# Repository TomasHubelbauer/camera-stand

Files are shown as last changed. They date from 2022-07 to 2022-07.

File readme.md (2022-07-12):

# Camera Stand

This repository hosts the development of a 3D model for a 3D printed part that
is used to mount my camera to use as a webcam behind my monitor.

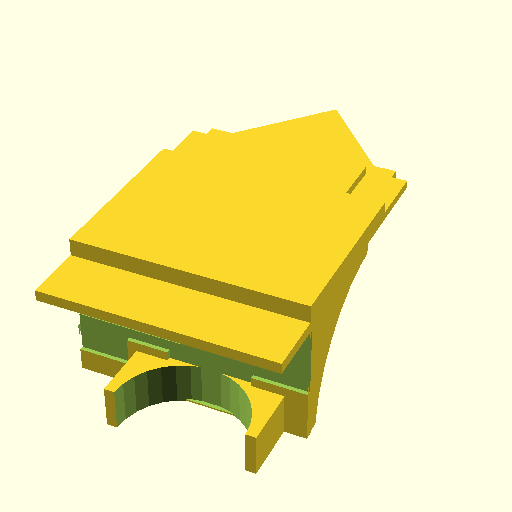
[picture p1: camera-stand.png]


## Status & Goal

This part should be complete now provided the test print fits.

The goal of this part is to be a mount that fits into the VESA mount of my
monitor and extends a flat platform onto which my camera can sit. The platform
has hole for the dummy battery power plug as well as a recess in the shape of
the camera's body so that the camera doesn't shift away from the central point
when I turn it on and off. The recess/track that fits the camera's body in the
flat of the platform also extends to make room for the camera's grip handle and
the lens which both extend to contour of the camera as projected on the surface.

## Process & Files

Note: this process is implemented in [`slice.sh`](slice.sh). The simplified
process now is to open OpenSCAD and VS Code side by side, make changes in VS
Code and see them reflect in OpenSCAD and on each iteration I am happy with run
`./slice.sh` which generates STL, slices it to GCode and export a 3MF directory
of the PrusaSlicer project file as well.

I use OpenSCAD to design the part. I split my screen into VS Code on the left
and OpenSCAD on the right. OpenSCAD is configured to hide the editor and with
this setting on, it will automatically refresh whenever the source file is
changed in VS Code. In VS Code, I use the OpenSCAD extension for VS Code for
syntax highlighting and auto-complete.

Once I am happy with the current iteration, I render the file out to an SLT in
OpenSCAD (configured to put out ASCII STL by default) and drag it into a new
project in PrusaSlicer. Next, I orient it for the speed of printing and less so
for the strength of the resulting part (since it is just an iteration for now)
and slice it there. Once sliced, I save the PrusaSlicer project and the GCode.

Since PrusaSlicer projects are 3MF files which are binary (they are [OPC] ZIP
archives of several files), I use a hand-made script that I run after I have
saved the 3MF file to extract it into a directory by the same name to help diff.

[OPC]: https://en.wikipedia.org/wiki/Open_Packaging_Conventions

- `slice.sh` is the script that generates GCode and 3MF directory (not file)
- `camera-stand.gcode` is the GCode generated by PrusaSlicer for my Prusa MK3S
- `camera-stand.png` is the OpenSCAD render of the model generated in `slice.sh`
- `camera-stand.scad` is the source code authored by me
- `camera-stand.stl` is the ASCII STL rendered out by OpenSCAD
- `camera-stand.3mf` is the directory where `./3mf-zip-dir` extracts PrusaSlicer
  project file by the same name (it is an OPC ZIP binary not fit for versioning)

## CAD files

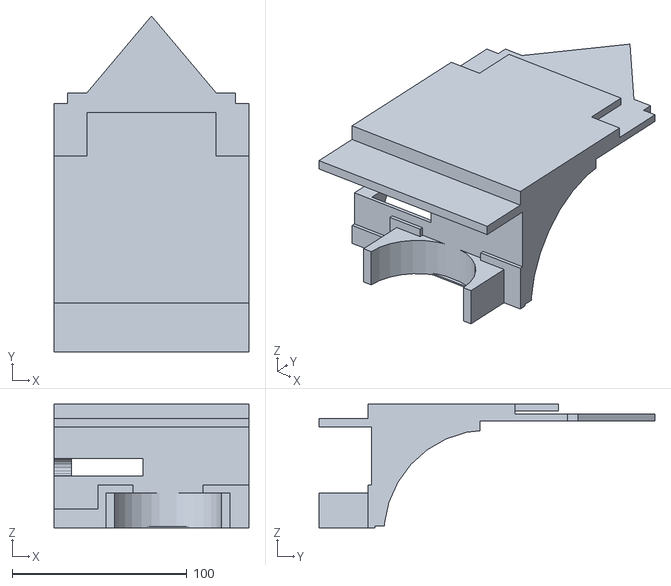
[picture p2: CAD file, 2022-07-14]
camera-stand.stl
111.2 x 192.0 x 70.7

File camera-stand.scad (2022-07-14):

// The distance between the right side of the left screw and left side of the
// right screw connecting the VESA mount plate and the screen (as seen when
// sitting in front of the screen)
screws_distance = 96;

// The distance between the top sides of the two flaps that presumably have the
// screw holes for the 75x75 mm version of the VESA mount
// This distance is important, because it is the maximum width for something to
// be able to slot between the screws and these flaps in order to go deep into
// the gap between the VESA mount plate and the back of the monitor.
flaps_distance = 74;

// The length of the surface of the flap beneath the screw that needs to be
// accounted for for the main rectangular leg to be narrower by in order to be
// able to slot deep into the gap between the VESA mount plate and the monitor
flap_width = (screws_distance - flaps_distance) / 2;

// The gap between the back of the screen and the flat side of the VESA mount
// plate facing the screen - the thickness of a support leg that fits there
plate_screen_gap = 4;

// The distance between the top point of the VESA mount plate arc and the top
// side of the left and right top screws connecting the plate and the screen
// (as seen when sitting in front of the screen)
tip_screw_distance = 30;

// The distance between the top point of the VESA mount and the top of the flaps
// on the plate that prevent slotting anything below this depth unless it is at
// most as wide as the distance between the flaps.
tip_flap_distance = 36;

// The depth between the top point of the VESA mount plate arc and the possible
// flaps that could collide with a box slotted in between the screen and the
// mount plate between the two top screws
// I've test-fitted to be up to 115 mm deep and there should be no other flaps
// so it theoretically can go all the way below the monitor, but there is only
// limited value to making this too large as there are diminishing returns on
// the snugness of the assembly compared to the printing time.
tip_pit_depth = 80;

// The diameter of a single screw used to calculate the gap between two parts
// that sit supported on and by the screw when bridged over their tops
screw_diameter = 3.6;

// The thickness of the VESA mount plate the two rectangular legs sit against
// the sides of
// This is not exact, I am affording some play for ease of slotting the part
// onto the edge of the plate, but not too much so it remains snug and sturdy.
plate_thickness = 1.7;

// The size of the square columns that sit at the outside of the top left and
// right screws of the VESA mount plate forming a hook together with the main
// rectangle leg and the surface that connects the three legs together to make
// a double hook
square_leg_size = 4;

// The distance from the left side to the right side of the whole leg assembly
// (left leg column, left screw, rectangular leg, right screw, right leg column)
leg_bridge_width = square_leg_size * 2 + screw_diameter * 2 + screws_distance;

// The thickness of the arch that connects the two main surfaces
brace_width = 10;

// The radius of the cylinder that cuts out the arch shape in the brace
arch_radius = 60;

// The rectangular leg that slots in between the screen back and the VESA mount
// plate on one axis and the two top screws on the plate on the other axis
linear_extrude(plate_screen_gap) polygon([
  // The origin point
  [0, 0],
  // The widest distance covering the length between the side square legs
  [leg_bridge_width, 0],
  // The first point that makes the bridge line over the screw
  [leg_bridge_width, tip_screw_distance],
  // The second point of the screw bridge line, shifted by screw width
  [leg_bridge_width - square_leg_size - screw_diameter, tip_screw_distance],
  // The surface that sits on the flap close to the screw over the flap's length
  [leg_bridge_width - square_leg_size - screw_diameter, tip_flap_distance],
  // The other side of the flap top surface that doesn't go deeper than this
  [leg_bridge_width - square_leg_size - screw_diameter - flap_width, tip_flap_distance],
  // The first point of the main rectangular leg that slots between the screws and flaps
  [leg_bridge_width / 2, tip_pit_depth],
  // The second point of the main rectangular leg that goes deep into the plate/screen gap
  [leg_bridge_width / 2, tip_pit_depth],
  // The first point of the top of the other flap that the rectangular leg is narrower by
  [square_leg_size + screw_diameter + flap_width, tip_flap_distance],
  // The second point of the top surface of the second flap next to the main leg
  [square_leg_size + screw_diameter, tip_flap_distance],
  // The first point over the bridge surface that makes the hook around the second screw
  [square_leg_size + screw_diameter, tip_screw_distance],
  // The second point over the second screw bridge layer, shifted by the screw diameter
  [0, tip_screw_distance],
]);

// The length of the channel the dummy battery plug goes into
gap_width = 50.6;

// The top surface that bridges the gap between the rectangular legs that hug
// the flat sides of the VESA mount plate
translate([0, -plate_screen_gap, 0]) cube([leg_bridge_width, plate_screen_gap, plate_screen_gap * 2 + plate_thickness]);

// The other rectangular leg that hugs the flat side of the VESA mount plate
// directed towards the wall as opposed to towards the back of the monitor
translate([square_leg_size + screw_diameter + flap_width, 0, plate_screen_gap + plate_thickness]) cube([flaps_distance, 25, plate_screen_gap]);

difference() {
  union() {
    // The vertical extension to raise the surface to the monitor top edge level
    translate([0, -84, 0]) cube([leg_bridge_width, 80, plate_screen_gap * 2 + plate_thickness]);

    track_offset = 12;
    track_size = 33;
    track_limit = track_offset + track_size;

    // The surface the camera sits on itself, perpendicular to the previous column
    difference() {
      translate([0, -84, -61]) cube([leg_bridge_width, 4, 70]);

      // The track in which the camera sits so it doesn't shift back and forth
      translate([0, -85, -3.5 - track_limit + track_offset]) cube([leg_bridge_width, 3, track_limit - track_offset]);
    
      // The cutout for the camera's grip handle to not crash with the track
      translate([0, -85, -2.3 - track_limit + track_offset - 15 + .1]) cube([25, 3, 15]);

      // The cutout for the camera's lens which also extends to the bottom plate
      translate([60 - (40 / 2) + 5, -85, -2.3 - track_limit + track_offset - 25 + .1]) cube([40, 3, 25]);
    }

    lens_diameter = 61;
    lens_radius = lens_diameter / 2;

    difference() {
      translate([60 - (40 / 2) + 5 + (40 / 2) - lens_radius - 5, -112, -61]) cube([lens_diameter + 10, lens_radius, 20]);
      translate([60 - (40 / 2) + 5 + (40 / 2), -112, -61.5]) cylinder(21, lens_radius, lens_radius);
    }

    plate_height = lens_radius - 2.5;
    back_thickness = 5;

    // The back plate for the camera to lean against without rocking back and forth
    translate([0, -84 - plate_height, -3.5]) cube([leg_bridge_width, plate_height, back_thickness]);
  }

  // A gap in the surface for the camera dummy battery power adapter plug to go through
  translate([-1, -85, -31.5]) cube([gap_width + 1, 10, 10]);
}

// The middle support arch holding the horizontal surface to the vertical column
difference() {
  translate([(leg_bridge_width - brace_width) / 2, -80, -arch_radius]) cube([brace_width, arch_radius, arch_radius]);
  translate([(leg_bridge_width - (brace_width + 2)) / 2, -15, -arch_radius - 5]) rotate([0, 90, 0]) cylinder(brace_width + 2, arch_radius, arch_radius);
}

// The left support arch holding the horizontal surface to the vertical column
difference() {
  translate([leg_bridge_width - brace_width, -80, -arch_radius]) cube([brace_width, arch_radius, arch_radius]);
  translate([leg_bridge_width - (brace_width + 2) + 1, -15, -arch_radius - 5]) rotate([0, 90, 0]) cylinder(brace_width + 2, arch_radius, arch_radius);
}

// The right support arch holding the horizontal surface to the vertical column
difference() {
  translate([0, -80, -arch_radius]) cube([brace_width, arch_radius, arch_radius]);
  translate([-1, -15, -arch_radius - 5]) rotate([0, 90, 0]) cylinder(brace_width + 2, arch_radius, arch_radius);
  translate([-1, -75, -26.5]) rotate([0, 90, 0]) cylinder(12, 5, 5);

  // The same gap as above to cut through the arch in addition to the platform
  translate([-1, -85, -31.5]) cube([gap_width + 1, 10, 10]);
}

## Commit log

2022-03-13 Design the basic shapes to test fit
    I measured the dimensions using a sheet of paper I kept cutting off piece by piece, because it is not easy to get access behind the screen with calipers and I am not going to dismount the screen to m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
    [camera-stand.scad, camera-stand.stl]
2022-03-13 Expand the PrusaSlicer 3MF project for tracking
    From now on with each change I will also track the unzipped version of the 3MF.
2022-03-13 Use the thumbnail in the readme and explain the flow
    I added a few words about how I work so it is clear why the 3MF directory exists and what is the source of truth: OpenSCAD > ASCII STL > 3MF directory.
2022-03-13 Include the script name in the readme
    The VS Code integrated terminal is good at remembering the last used command, so I don't need to type the script name a whole lot, but in case I ever do and I don't feel like typing or tabbing, it is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
2022-03-13 Configure the GCode file name format for better versioning
    By default the format contains variable stuff that would result in carrying multiple versions of the file side by side, instead of carrying a history of a single file. By changing the format to use just the file name, this is avoided.
    This is configured in Print Settings (Expert) > Output file > Output filename format.
2022-03-13 Track the PrusaSlicer generated GCode
    I have finally figured out how to track the project file so now I was able to slice the model and here is the GCode for my printer. The next revisions will have SCAD, STL, 3MF and GCODE file changes 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
2022-03-13 Change to a fit testing box for the new layout idea
    The monitor mount has two parts which connect using a track for one to go into the other and are secured together using screws. I did not have these screws there and tightened before. I added them and now the distance between the mount plate and the wall is much shorter so the previous revision doesn't fit at all. I've decided to change course and instead print a stand that will only attach to the mount part that is secured to the monitor not primarily the one attached to the wall.
    [camera-stand.scad, camera-stand.stl]
2022-03-13 Update dimensions and form into a hook platform over the VESA mount
    I need to learn to use the calipers properly, because the previous fit test box was too short on the X (but the other dimensions were correct).
    This shape should be able to sit snugly on the VESA mount edge and secured by the two screws so it doesn't move in any direction.
    [camera-stand.scad, camera-stand.stl]
2022-03-13 Revert the GCode file name config
    I tend to start a new PrusaSlicer project and just delete the 3MF directory in this repository, save the new project and rebuild it.
    This setting is not preserved when I create a new project and I have found it is not too much of an issue since I can just select the old GCode file when exporting GCode and it will take its name and replace it, so the default suggested name is no problem. The modal window even remembers the last directory, so it is quite literally only a single click to solve this problem.
    I could probably set this in some sort of a profile file and have it be the default for new prints, but I don't want that for prints that are not versione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
2022-03-13 Split the readme into Status and Process sections
    The process section is important so that I can remember this workflow if I ever get back to this at a later date.
    The status section captures the goal as well as the current state of the part as it is undergoing development. Once done, I will reflect that in this section.
2022-03-13 Redesign the rectangular slot that goes between the screen and the mount
    I have messed up before, the screw slots need to be at the right distance from the tip of the plate arc, not right beneath its level. I've reduced the design to just this slot for now and I will tweak it until it is good and then continue designing for the other part of the plate.
    [camera-stand.scad, camera-stand.stl]
2022-03-13 Increase screw diameter for clearance and add opposite side rectangular leg
    The screw slot is too tight because I made it the exact screw diameter and the nozzle diameter is not a perfect division of that number. I added an extra give hoping to accomodate the screws better.
    I also added a draft slot for the leg on the opposite side of the VESA mount plate.
    [camera-stand.scad, camera-stand.stl]
2022-03-13 Increase screw diameter for even more clearance and shrink back plate
    The screw slots still do not fit snugly around the screw so I've bumped the clearance up even more. On top of this, I have shrunk the back plate to make sure it does not collide with the flaps coming up from the plate, which would probably not happen with its current depth but would have happened if I prolonged it later.
    [camera-stand.scad, camera-stand.stl]
2022-03-14 Print plate-screen gap depth test fit piece in vase mode
    I know the dimensions of the gap in two axes which give me the rectangular main leg footprint, however, I don't know how deep this gap can go, so I'm trying to see if 100 mm is too much or will still fit.
    I have measured the distance between the flaps on the mount plate, it is 75 mm as compared to the distance between the screws, which is 96 mm. This means the main leg needs to be at most 75 mm thick, not 96 mm, after a certain depth (the distance between the flaps and the screws). I have not measured this exact depth yet, will do so after the test fit.
    I'm printing with no top or bottom solid layers or infill and in vase mode so I g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
    [camera-stand.scad, camera-stand.stl]
2022-03-14 Shape the main leg accounting for the flaps
    Now that I have measured the relevant dimensions, I am able to make the main rectangular leg narrower to avoid colliding with the flaps in the VESA mount (that I presume are there to support its 75x75 mm variant as opposed to 100x100 mm I am using).
    I am still printing in vase mode, but I have added a single solid bottom layer to make sure the shape really fits and the outline doesn't just get squished. I might need to make the leg one bit more narrow if it doesn't after this test fit.
    [camera-stand.scad, camera-stand.stl]
2022-03-14 Increase flap distance to make the model fit
    Previous test fit did not go accoding to plan, it seems the value for the flap distance I measured on the other side of the plate previously when making the other, currently hidden flat rectangular leg, is a better fit.
    I might adjust this even more if this still won't fit.
    [camera-stand.scad, camera-stand.stl]
2022-03-14 Add the other rectangular leg to test fit both at the same time
    The width of the rectangular leg is 74 mm as verified by the last test fit. I am winding a 1.6 mm mount plate thickness as 2 mm seemed to have too much give. I've also made the other rectangular leg go a bit deeper into the mount edge, but left room so that it would for sure fit. This whole assembly should fit now. If it does, it will be time to add the spacer part and the top flat layer to sit the camera on to it.
    [camera-stand.scad, camera-stand.stl]
2022-03-14 Reorient for slower printing but without irremovable supports
    I made a mistake trying to print the part laying flat before, because the support in the thin slot was impossible to remove and I permanently bent the part with still some support left trying to do it. I will print in a standing orientation now and to prevent layer shifting and other bad stuff, I have increased perimeter enough so that only the base will have infill and the rest of the model will be solid inside. This should give it enough strength to print cleanly and last. I have also added a lot of brim hoping it would help keep the object steady while printing.
    [camera-stand.scad, camera-stand.stl]
2022-03-16 Simplify the shape of the main leg for faster printing
    This triangular shape will make it easier to fit between the screws and the flaps and the bridge surfaces over the screws and the flaps should still keep the piece level and sturdy. Maybe this triangular part could be forgone completely and sturdiness could be derived solely from the fit over the edge of the mount plate, but I don't want to rely on that alone yet as I am still experimenting with the plate thickness which will make the piece fit easily but not have too much play.
    I have not updated the 3MF and the GCode as I am not printing this, I will adjust the plate thickness in the next commit and do a test print then.
    [camera-stand.scad, camera-stand.stl]
2022-03-16 Increase gap for plate side mounting
    I have removed the dimension to make this part slottable into another, I am thinking I will print this as a single part after all since the gap depth does not need to extend all so much.
    I have updated PrusaSlicer which changed the settings diff a little bit, but that's unrelated to the geometry change.
    [camera-stand.scad, camera-stand.stl]
2022-03-18 Extend the stand to make camera level at monitor top edge
    I have pretty much eyeballed these dimensions and I am going to print for a test fit now.
    The hole is there to make room for the wall plug of the dummy battery adapter.
    [camera-stand.scad, camera-stand.stl]
2022-03-18 Shift and enlarge top surface and add support brace
    I think I have the height sort of okay, but the previous extension of the surface to both sides made it crash to the wall and also I misplaced the dummy battery plug hole. The hole would still have been okay, just weirdly placed, but the crashing of the surface to the wall caused the whole assembly to not be able to fit onto the edge of the mount plate.
    It was also too narow so the camera would cause it to tip forward and since I had to break off the support flap on the back, it would not resist because it was not holding onto both sides of the mount plate.
    I was not sure whether the surface would be able to hold the weight of the camera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
    [camera-stand.scad, camera-stand.stl]
2022-03-31 Enlarge the gap for the power plug
    The power club is not straight but angled and as of current it doesn't fit great into the gap and it limits the camera's movement a lot. A larger gap should allow more maneuverability and if it is still not enough, I wil instead make it a straight-up cutout.
    [camera-stand.scad, camera-stand.stl]
2022-07-12 Make the gap the right size for the plug and enlarge the support arch
    I think I finally have the dimensions down for the plug. At least I hope so. The arch I made larger because there is nothing preventing it from being larger in terms of obstructing from the screen and it looks better this way.
    [camera-stand.scad, camera-stand.stl]
2022-07-12 Cut out tracks for the contour of the camera's body
    The track includes the body itself as well as the hand grip and the lens which both need room to not clash with the surface as the camera body sinks the 2 mm into the track cutout.
    [camera-stand.scad, camera-stand.stl]
2022-07-12 Update the readme with current status and clear done todos
    The part should be done now provided the test print fits.
2022-07-13 Add a wall the camera can lean against to sit in the cradle
    This wall is there to prevent the camera from rocking back when removing and putting back the lens cover as well as to provide additional support for when the hot shoe light cube is being turned on and off (which puts downward and slightly back-facing pressure on the camera).
    [camera-stand.scad, camera-stand.stl]
2022-07-13 Adjust the position of the lens track cutout
    It was off center and according to my measurements, a 5 mm shift to the right should just about fix it.
    [camera-stand.scad, camera-stand.stl]
2022-07-13 Triplicate the support arches
    I returned the original thickness as I think it will look better after all and also decided to triplicate the arch as I think it will help with the downward pressure applied to the camera as I turn o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
    [camera-stand.scad, camera-stand.stl]
2022-07-13 Fix the dummy battery plug hole dimensions
    I goofed out and placed the hole over the area where the plug cover rotates over to when the camera plug is exposed, but the area where the plug hole and the plug on the cable connect together was not accounted for. Also the cable and the plug on it need room to bend out of the way. I made the slit wide enough to accomodate for all this now - I hope.
    [camera-stand.scad, camera-stand.stl]
2022-07-13 Fix grip recess width and add a lens cradle
    I brought the height of the back plate to the same height as the top of the lens cradle so that these are the pivot points for the assembly to stand on when printing.
    I have enable supports as the surface the camera sits on is no longer flat.
    [camera-stand.scad, camera-stand.stl]
2022-07-13 Re-slice with PrusaSlicer 2.4.2
    I have updated and there seems to be some improvements to slicing so I am reslicing before the print to take advantage of these.
    [camera-stand.stl]
2022-07-13 Move the back plate front by 1 mm
    Seems like there is a bit of play that this could reduce.
    [camera-stand.scad, camera-stand.stl]
2022-07-13 Shift the camera power port gap to actually match the port
    It was shifted so that only half of the port was visible through the hole.
    [camera-stand.scad, camera-stand.stl]
2022-07-13 Adjust the camera grip handle cutout size
    It can be smaller as evident from the latest test fit so let's make it smaller.
    [camera-stand.scad, camera-stand.stl]
2022-07-14 Move the back plane some more adjusting the track
    Previously when I moved the plate I did not adjust the track which means I just shifted the space.
    [camera-stand.scad, camera-stand.stl]
2022-07-14 Adjust the dummy battery hole some more
    I made it so it sits flush between the two arches as well as shifted it forward a bit which it still needed to be after the last test fit.
    [camera-stand.scad, camera-stand.stl]
2022-07-14 Add a side cutout for the dummy battery power cable to maybe go through
    I am not sure if it will fit through such a small space, but it is worth a shot.
    [camera-stand.scad, camera-stand.stl]
2022-07-14 Adjust the power plug channel to extend beyond the edge
    The hole in the arch I made before was too small to fit the connector through, but with a channel like this, I think it will work out nicely.
    [camera-stand.scad, camera-stand.stl]
2022-07-14 Add a TODO for locating slicer config automatically and using tree supports once released
    Both will be good improvements but especially tree supports should help a lot with the print time.
2022-07-14 Switch to snug supports for a slightly faster print
    I think these will be enough.
    [camera-stand.stl]
2022-07-14 Expand the arches and move the channel deeper into its own for more room
    The cutout for the power plug to go through the arch was not deep enough, but going deeper alone would have split the arch into two parts essentially cancelling out its function, so I made all three 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
    [camera-stand.scad, camera-stand.stl]
